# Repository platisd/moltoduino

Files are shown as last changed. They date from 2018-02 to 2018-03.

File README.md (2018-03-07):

# Moltoduino
Add programmable cores to your project and enable Hardware In the Loop (HIL) testing.

Stacked Moltoduinos

## What?
Moltoduino is an Arduino shield that enables the stacking of multiple ATMega328P microcontrollers. The microcontroller pins are broken out in two ways:
* Outwards, to enable their arbitrary connection to different components or other pins via cables.
* Inwards, to enable their connection to the respective pin of the bottommost Arduino via jumpers.

The firmware on the Moltoduino cores can be easily flashed by flipping a switch that sets them in programming mode and then using the bottommost Arduino as an ISP programmer. You can read more about the project on [platis.solutions](https://platis.solutions/blog/2018/02/22/moltoduino-extra-cores-hil-testing/).

## Why?
Moltoduino is essentially a barebones Arduino UNO in the form of a shield that can be easily reprogrammed. So, what can you do with it?

* Parallelize time-consuming or time-critical functionality (e.g. reading sensor data, playing sound)
* Have a dedicated microcontroller for computationally intensive operations (e.g. Fast Fourier Transform)
* Enable Hardware In the Loop (HIL) testing
* Get additional resources, such as I/O pins, external interrupts, Serial port, I2C bus etc
* Save physical space needed for applications that require a more than one microcontrollers (e.g. by stacking them instead placing them next to each other)

## How?
Moltoduino was initially created with the purpose of providing a stackable pin extension solution for Arduino boards. During development, another use case emerged which involved the shield being used for HIL testing.

The picture below illustrates how the pins of the shield's ATMega328P are broken out, highlighting them with **green**. In **red** one can find the bottom Arduino's pins. It becomes apparent that pins that follow the Arduino numbering convention can be easily connected via jumpers (e.g. D1 with D1) regardless of which specific Arduino board is in place (i.e. Mega or Uno). Furthermore, the shield's pins are also broken on the sides of the board so to be accessible when multiple Moltoduinos or other shields are stacked on top.

Moltoduino pin grouping

### Pin extension
Attaching a Moltoduino shield is more or less equivalent to placing an Arduino Uno on top of another Uno or Mega board. The cool part is that it doesn't take up any horizontal real estate. You program them to perform an individual task in parallel or connect the Arduinos together via Serial, I2C or otherwise to implement complex functionality.

The pins facing outward can interface with the external components while the inward facilitate connection to the bottom Arduino, especially via I2C or Serial.

### HIL testing
Moltoduino can be utilized to provide a _hobby-grade_ [HIL testing](http://www.hil-simulation.com/home/hil-testing.html) solution for your embedded project. Having two microcontrollers that are easily connected to each other it is possible to conduct HIL simulations. This is achieved by one microcontroller running the production code and the other running the HIL test which generates input for the system under test and reads its output.

Such a HIL test fixture allows you to automate system-level testing on your project by mimicking real-world input. This can be a difficult and laborious process, where the tester would have to manually provide the environment input and check the output so to verify the system. Check out the relevant [code examples](#code-examples) to see how a HIL implementation could look like.

### Programming Moltoduino
1. Have all switches (there is one on each Moltoduino), in the "operation" position instead of "programming" mode
2. In the Arduino IDE, upload the **ArduinoISP** sketch to the "bottom" Arduino
3. Open the sketch to upload to the Nth Moltoduino on the Arduino IDE
4. Make sure that "Arduino as ISP" is chosen under **Tools** :arrow_right: **Programmer**
5. Choose the Arduino Uno as the target board, under **Tools** :arrow_right: **Board** :arrow_right: **Arduino/Genuino UNO**
6. Put the switch in the "programming" position, on the Moltoduino(s) you wish to program
7. (If not previously done) Burn the bootloader, under **Tools** :arrow_right: **Burn bootloader**
8. Upload sketch using programmer, under **Sketch** :arrow_right: **Upload sketch using programmer**
9. Put the switch back in the "operation" position, otherwise uploading to the bottom Arduino will not be possible

## Code examples
For the code examples the [Smartcar shield](http://plat.is/smartcar) library will be used. You can easily download it via your Arduino IDE library manager.

### Controlling a Smartcar via UART
In this scenario, a [Smartcar](http://plat.is/smartcar) is being controlled via UART (e.g. an HC-06 Bluetooth dongle) and we want to verify its behavior. The HIL simulation will be running on an Arduino Mega while the system under test firmware will be uploaded onto a Moltoduino that is stacked on top.

**System under test**

The following code should be straight forward. Depending on the UART input the Smartcar should change speed and direction. We are steering the Smartcar with a servo motor while the speed is controlled by a brushed motor. We will be sending commands via UART and reading the PWM steering signal as well as the brushed motor control signals in order to verify the Smartcar's intended behavior.

```cpp
#include <Smartcar.h>

const int SERVO_PIN = 3;
const int FORWARD_PIN = 8;
const int BACKWARD_PIN = 7;
const int THROTTLE_PIN = 6;
const int fSpeed = 70; // 70% of the full speed forward
const int bSpeed = -70; // 70% of the full speed backward
const int lDegrees = -50; // Degrees to turn left
const int rDegrees = 50; // Degrees to turn right

// Initialize the car, that uses a servo motor for steering
// and a brushed DC motor to pins 8,7 (direction) and 6 (PWM) for throttling
Car car(useServo(SERVO_PIN), useDCMotor(FORWARD_PIN, BACKWARD_PIN, THROTTLE_PIN));

void setup() {
  Serial.begin(9600);
  car.begin(); // Initialize the car using the encoders and the gyro
}

void loop() {
  handleInput();
}

void handleInput() { // Handle serial input if there is any
  if (Serial.available()) {
    char input = Serial.read();
    switch (input) {
      case 'l': // Turn counter-clockwise going forward
        car.setSpeed(fSpeed);
        car.setAngle(lDegrees);
        break;
      case 'r': // Turn clock-wise
        car.setSpeed(fSpeed);
        car.setAngle(rDegrees);
        break;
      case 'f': // Go ahead
        car.setSpeed(fSpeed);
        car.setAngle(0);
        break;
      case 'b': // Go back
        car.setSpeed(bSpeed);
        car.setAngle(0);
        break;
      default: // If you receive something that you don't know, just stop
        car.setSpeed(0);
        car.setAngle(0);
    }
  }
}
```

**HIL simulation**

In this HIL test we need to simulate the input to the system (i.e. UART commands) and then observe its output (i.e. pin states and PWM signal) to verify production code's correct behavior. Moreover, jumpers are used to enable interaction between the system under test and the HIL simulation. The jumper placement is illustrated in the table below.

| HIL simulation | System Under Test | Purpose |
| :----: |:----: |:----: |
| TX |  RX | Transmit UART commands to the SUT |
| 3 |  3 | Read servo motor's PWM signal |
| 7 |  7 | Read motor control pin |
| 8 |  8 | Read motor control pin |

```cpp
// Simulation pin configuration
const int STEERING_PIN = 3;
const int FORWARD_PIN = 8; // Car goes forward when set HIGH
const int BACKWARD_PIN = 7; // Car goes backward when set HIGH
const int THROTTLE_PIN = 6;
// UART commands
const char CAR_FORWARD = 'f';
const char CAR_BACKWARD = 'b';
const char CAR_LEFT = 'l';
const char CAR_RIGHT = 'r';
const char CAR_STOP = 's';
// Expected steering degrees
const int LEFT = -50;
const int RIGHT = 50;
const int STRAIGHT = 0;
// Other variables and structures
enum Throttle {
  FORWARD,
  BACKWARD,
  STOPPED,
};

bool isThrottle(Throttle expectedThrottle) {
  Throttle actualThrottle = STOPPED;
  if (digitalRead(FORWARD_PIN) && !digitalRead(BACKWARD_PIN)) {
    actualThrottle = FORWARD;
  } else if (!digitalRead(FORWARD_PIN) && digitalRead(BACKWARD_PIN)) {
    actualThrottle = BACKWARD;
  }

  return actualThrottle == expectedThrottle;
}

bool isSteering(int expectedAngle) {
  int pwm = pulseIn(STEERING_PIN, HIGH);
  // Map the PWM signal to a 0 to 180 scale
  const int MIN_PWM = 540;
  const int MAX_PWM = 2390;
  int measuredAngle = map(pwm, MIN_PWM, MAX_PWM, 0, 180);
  // Offset the angle by 90 to get an angle between -90 and 90
  measuredAngle -= 90;
  int absoluteDelta = expectedAngle > measuredAngle ?
                      expectedAngle - measuredAngle : measuredAngle - expectedAngle;
  // We are expecting some error in these measurements so let's define an acceptable error margin
  const int ERROR_MARGIN = 5;

  return absoluteDelta < ERROR_MARGIN;
}

void runSmartcarHIL(const char* testName, const char command, Throttle throttle, const int steering) {
  Serial.print("RUNNING: ");
  Serial.println(testName);
  // Send command
  Serial.print("Sending command: ");
  Serial.print(command);
  Serial.flush(); // Make sure we have finished sending
  // Wait a bit to make sure the command has been processed
  const unsigned long TEST_DELAY = 100;
  delay(TEST_DELAY);
  String result = isThrottle(throttle) && isSteering(steering) ? "PASSED" : "FAILED";
  Serial.print("\nRESULT: ");
  Serial.println(result);
  Serial.println("----");
}

void goForward_test() {
  auto UARTcommand = CAR_FORWARD;
  auto expectedThrottle = FORWARD;
  auto expectedSteering = STRAIGHT;
  runSmartcarHIL(__func__, UARTcommand, expectedThrottle, expectedSteering);
}

void goBackward_test() {
  auto UARTcommand = CAR_BACKWARD;
  auto expectedThrottle = BACKWARD;
  auto expectedSteering = STRAIGHT;
  runSmartcarHIL(__func__, UARTcommand, expectedThrottle, expectedSteering);
}

void turnLeft_test() {
  auto UARTcommand = CAR_LEFT;
  auto expectedThrottle = FORWARD;
  auto expectedSteering = LEFT;
  runSmartcarHIL(__func__, UARTcommand, expectedThrottle, expectedSteering);
}

void turnRight_test() {
  auto UARTcommand = CAR_RIGHT;
  auto expectedThrottle = FORWARD;
  auto expectedSteering = RIGHT;
  runSmartcarHIL(__func__, UARTcommand, expectedThrottle, expectedSteering);
}

void stop_test() {
  auto UARTcommand = CAR_STOP;
  auto expectedThrottle = STOPPED;
  auto expectedSteering = STRAIGHT;
  runSmartcarHIL(__func__, UARTcommand, expectedThrottle, expectedSteering);
}

void setup() {
  pinMode(FORWARD_PIN, INPUT);
  pinMode(BACKWARD_PIN, INPUT);
  pinMode(STEERING_PIN, INPUT);
  Serial.begin(9600);
  Serial.println("====================");
  Serial.println("Starting HIL test suite");
  Serial.println("====================");

  goForward_test();
  goBackward_test();
  turnLeft_test();
  turnRight_test();
  stop_test();
}

void loop() {
}
```

### Controlling a light based on ultrasound sensor distance measurements
In this scenario, an `HC-SR04` ultrasound sensor is being used to measure distances. When an object is detected close enough a light turns on. Yet again, the HIL simulation will be running on an Arduino Mega while the system under test firmware will be uploaded onto a Moltoduino that is stacked on top.

**System under test**

Below you can find a simplified implementation of the typical use case in which a light needs to be turned on when an object is detected at a nearby distance otherwise it should be off. The `HC-SR04` class of [Smartcar shield](http://plat.is/smartcar) library is utilized to conduct the measurements.

```cpp
#include <Smartcar.h>

SR04 sensor;
const int TRIGGER_PIN = 2;
const int ECHO_PIN = 3;
const int LIGHT_PIN = 9;
const int MIN_OBSTACLE_DISTANCE = 15; // In centimeters

void setup() {
  sensor.attach(TRIGGER_PIN, ECHO_PIN);
  pinMode(LIGHT_PIN, OUTPUT);
}

void loop() {
  auto distance = sensor.getDistance();
  // If there is an obstacle nearby turn the light on
  if (distance > 0 && distance < MIN_OBSTACLE_DISTANCE) {
    digitalWrite(LIGHT_PIN, HIGH);
  } else {
    digitalWrite(LIGHT_PIN, LOW);
  }
  delay(100);
}
```

**HIL simulation**

In this HIL test we need to simulate the `HC-SR04` ultrasound sensor's input to the system and then observe its output (i.e. the pin that controls the state of the light). Particularly, we observe (via an interrupt) the incoming signals from the trigger pin of the system under test, an event which designates that a measurement has been initiated. Next, we simulate the sensor input by calculating and producing a pulse of equal length to the one that would have been generated, should there have been an actual sensor and an object. Finally, we verify the digital pin that controls the light is in the appropriate state.

Jumpers are used to enable interaction between the system under test and the HIL simulation. The jumper placement is illustrated in the table below.

| HIL simulation | System Under Test | Purpose |
| :----: |:----: |:----: |
| 2 |  2 | Read trigger signal  |
| 3 |  3 | Generate echo pulse  |
| 9 |  9 | Read light pin state |

```cpp
const int TRIGGER_PIN = 2;
const int ECHO_PIN = 3;
const int LIGHT_PIN = 9;

volatile unsigned long echoDuration = 0;

void generateEcho() {
  if (echoDuration == 0) {
    // If no echo duration has been set or set to 0
    // then return immediately as no pulse is to be generated
    return;
  }
  digitalWrite(ECHO_PIN, LOW); // Set LOW first for cleaner signal
  delayMicroseconds(3);
  // Simulate the echo pulse of an HC-SR04 sensor
  digitalWrite(ECHO_PIN, HIGH);
  delayMicroseconds(echoDuration);
  digitalWrite(ECHO_PIN, LOW);
}

/**
   Accordig to the HC-SR04 datasheet (https://goo.gl/b22dp3) the formula to
   determine the distance in centimeters is: cm = uSec / 58
   We need to calculate the length of the pulse in microseconds
   that we has to be generated to simulate a specific distance in cm.
*/
void setEchoPulseDurationFor(unsigned int cm) {
  noInterrupts();
  echoDuration = cm * 58;
  interrupts();
}

void runUltrasoundHIL(const char* testName, int obstacleDistance, int expectedLEDState) {
  Serial.print("RUNNING: ");
  Serial.println(testName);
  setEchoPulseDurationFor(obstacleDistance);
  const unsigned long TEST_DELAY = 300;
  delay(TEST_DELAY); // Wait a bit for a new measurement to start
  String result = digitalRead(LIGHT_PIN) == expectedLEDState ? "PASSED" : "FAILED";
  Serial.print("\nRESULT: ");
  Serial.println(result);
  Serial.println("----");
}

void whenObstacleNear_lightTurnsOn_test() {
  auto obstacleDistance = 10;
  auto expectedLEDState = HIGH;
  runUltrasoundHIL(__func__, obstacleDistance, expectedLEDState);
}

void whenObstacleFar_lightTurnsOff_test() {
  auto obstacleDistance = 15;
  auto expectedLEDState = LOW;
  runUltrasoundHIL(__func__, obstacleDistance, expectedLEDState);
}

void whenNoObstacle_lightTurnsOff_test() {
  auto obstacleDistance = 0;
  auto expectedLEDState = LOW;
  runUltrasoundHIL(__func__, obstacleDistance, expectedLEDState);
}

void setup() {
  pinMode(LIGHT_PIN, INPUT);
  pinMode(TRIGGER_PIN, INPUT);
  pinMode(ECHO_PIN, OUTPUT);
  // Setup interrupt for trigger pin which goes HIGH when a measurement begins
  attachInterrupt(digitalPinToInterrupt(TRIGGER_PIN), generateEcho, FALLING);
  Serial.begin(9600);
  Serial.println("====================");
  Serial.println("Starting HIL test suite");
  Serial.println("====================");

  whenObstacleNear_lightTurnsOn_test();
  whenObstacleFar_lightTurnsOff_test();
  whenNoObstacle_lightTurnsOff_test();
}

void loop() {
}
```

## Bill Of Materials
| Quantity | Value | Device | Package |
|---|--- |---|---|
| 1 | Moltoduino PCB | ARDUINO_R3_ICSP | ARDUINOR3_ICSP |
| 1 | ATMEGA328P_PDIP  | ATMEGA328P_PDIP | DIL28-3 |
| 1 | BC547 | TRANSISTOR_NPNBC547 | TO-92-AMMO |
| 3 | 100nf | DIP-CERAMIC-DISC-100NF-50V-Y5V(D5.0MM) | CERAMIC-2.54 |
| 1 | 150Ω | DIP-RES-1K-5%-1/4W(PR-D2.3XL6.5MM) | PR-D2.3XL6.5MM |
| 1 | 16MHZ | DIP-CRYSTAL-16MHZ-18PF-30PPM-50R(HC49US)  | HC49US |
| 1 | 1K | DIP-RES-1K-5%-1/4W(PR-D2.3XL6.5MM) | PR-D2.3XL6.5MM |
| 2 | 22pf | DIP-CERAMIC-DISC-22PF-50V-10%-NPO(D4.0MM) | CERAMIC-2.54 |
| 1 | 2x16p-2.54 | DIP-BLACK-MALE-HEADER-VERT(2X16P-2.54) | H2X16-2.54 |
| 1 | 2x6p-2.54 | DIP-BLACK-MALE-HEADER(2X6P-2.54) | H2X6-2.54 |
| 2 | 4.7K | DIP-RES-4.7K-5%-1/4W(PR-D2.3XL6.5MM) | PR-D2.3XL6.5MM |
| 4 | 7p-2.54-90d | DIP-BLACK-MALE-HEADER(7P-2.54-90D) | H7-2.54-90D-MALE |
| 1 | AD595AQ-DIP14 | 74HC4066(DIP14) | DIP14-2.54-17.24X6.35MM |
| 1 | SK-12D01 | DIP-TOGGLE-SWITCH-ON-ON(3+2P-8.8X4.6MM) | SW5-2.0-8.8X4.4X4.7MM-90D |
| 1 | SR302DC | DIP-LED-RED-RED(2P-D3MM) | LED2-2.54-D3.0MM |
| 1 | TS-1101F | DIP-BUTTON-FRONT-WHITE(2P-3.4X6MM) | SW2-3.4X6.0X3.55MM-90D |

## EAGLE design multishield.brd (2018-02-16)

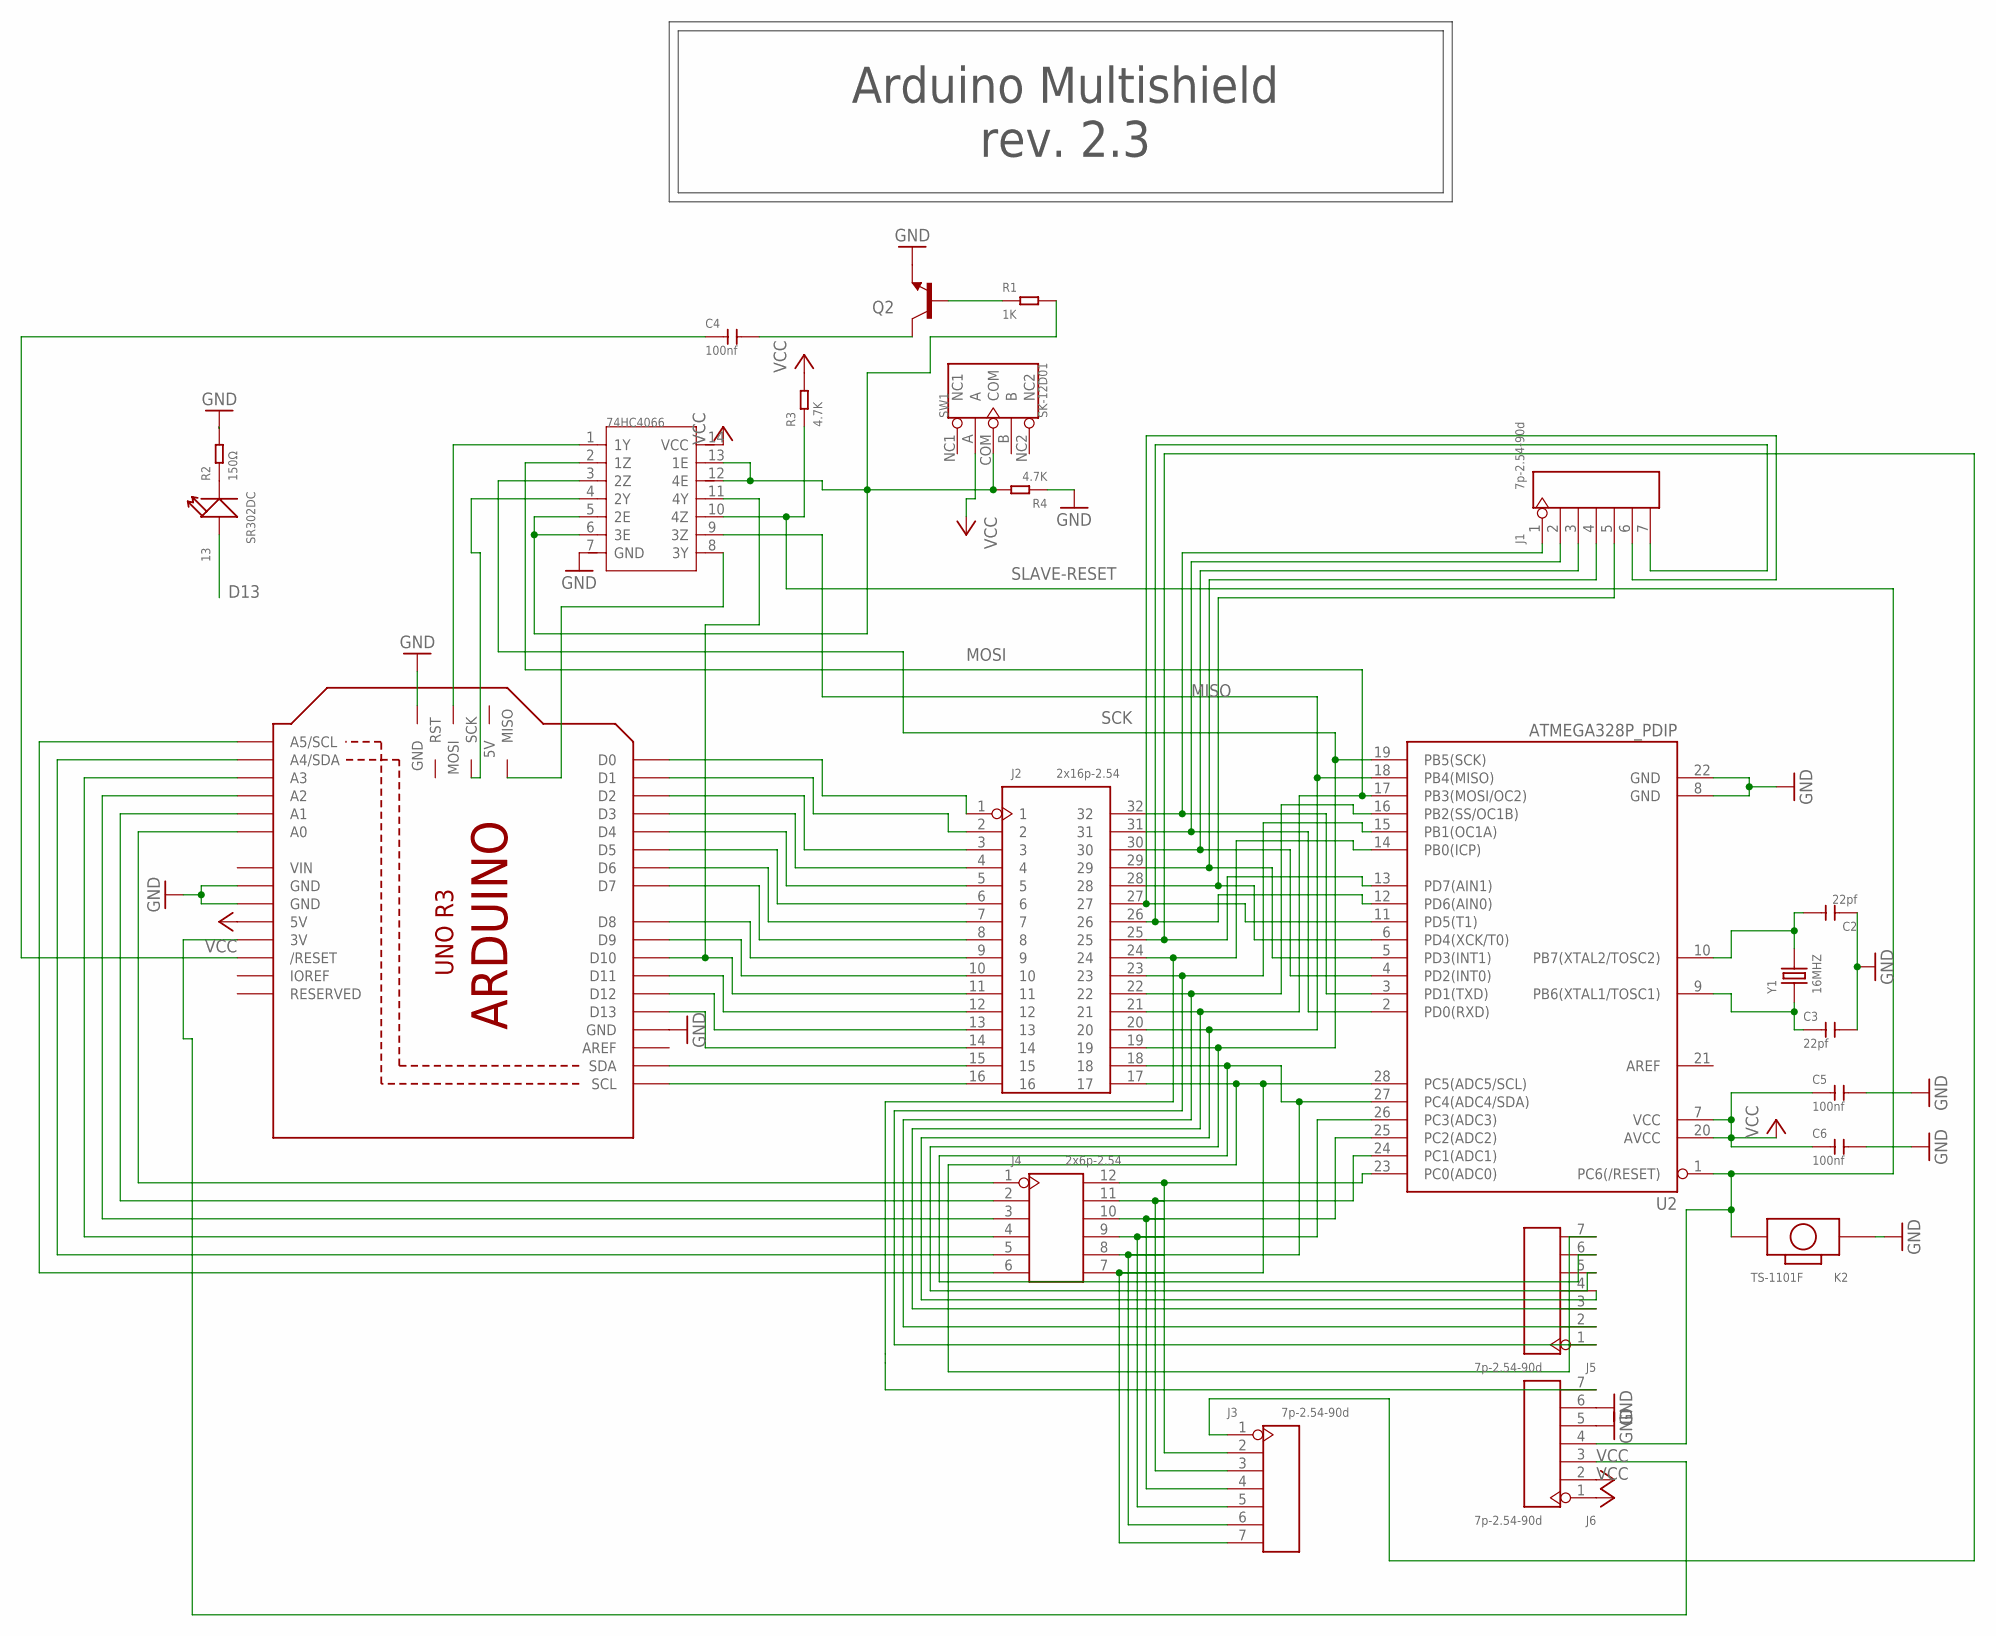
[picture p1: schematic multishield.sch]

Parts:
13: SR302DC; LED2-2.54-D3.0MM
C2, C3: 22pf; CERAMIC-2.54
C4, C5, C6: 100nf; CERAMIC-2.54
J1, J3, J5, J6: 7p-2.54-90d; H7-2.54-90D-MALE
J2: 2x16p-2.54; H2X16-2.54
J4: 2x6p-2.54; H2X6-2.54
K2: TS-1101F; SW2-3.4X6.0X3.55MM-90D
M1: ARDUINO_R3_ICSP; ARDUINOR3_ICSP
Q2: TRANSISTOR_NPNBC547; TO-92-AMMO
R1: 1K; PR-D2.3XL6.5MM
R2: 150Ω; PR-D2.3XL6.5MM
R3, R4: 4.7K; PR-D2.3XL6.5MM
SW1: SK-12D01; SW5-2.0-8.8X4.4X4.7MM-90D
U1: AD595AQ-DIP14; DIP14-2.54-17.24X6.35MM
U2: ATMEGA328P_PDIP; DIL28-3
Y1: 16MHZ; HC49US

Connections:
D9A: J2.10, M1.D9
D9B: J2.23, J5.1, U2.15 (PB1(OC1A))
GND: C2.1, C3.2, C5.2, C6.2, J6.5, J6.6, K2.P$1 (1), M1.GND, M1.GND@1 (GND), M1.GND@2 (GND), M1.GND@3 (GND), Q2.3 (E), R2.2, R4.1, U1.7 (GND), U2.8 (GND), U2.22 (GND)
MISO: J2.20, J5.4, U1.9 (3Z), U2.18 (PB4(MISO))
MOSI: J2.21, J5.3, U1.2 (1Z), U2.17 (PB3(MOSI/OC2))
unnamed: J2.1, M1.D0
unnamed: J2.2, M1.D1
unnamed: J2.3, M1.D2
unnamed: J2.4, M1.D3
unnamed: J2.5, M1.D4
unnamed: J2.6, M1.D5
unnamed: J2.7, M1.D6
unnamed: J2.8, M1.D7
unnamed: J2.9, M1.D8
unnamed: 13.K (-), R2.1
unnamed: J2.11, M1.D10, U1.11 (4Y)
unnamed: J2.12, M1.D11
unnamed: J2.13, M1.D12
unnamed: J2.14, M1.D13
unnamed: J2.15, M1.SDA
unnamed: J2.16, M1.SCL
unnamed: J1.1, J2.32, U2.3 (PD1(TXD))
unnamed: J1.2, J2.31, U2.2 (PD0(RXD))
unnamed: J1.3, J2.30, U2.4 (PD2(INT0))
unnamed: J1.4, J2.29, U2.5 (PD3(INT1))
unnamed: J1.5, J2.28, U2.6 (PD4(XCK/T0))
unnamed: J1.6, J2.27, U2.11 (PD5(T1))
unnamed: J4.1, M1.A0
unnamed: J2.25, J3.1, U2.13 (PD7(AIN1))
unnamed: J2.24, J6.7, U2.14 (PB0(ICP))
unnamed: J2.22, J5.2, U2.16 (PB2(SS/OC1B))
unnamed: C4.2, Q2.1 (C)
unnamed: C4.1, M1.RESET (/RESET)
unnamed: Q2.2 (B), R1.1
unnamed: M1.MOSI, U1.1 (1Y)
unnamed: M1.SCK, U1.4 (2Y)
unnamed: J1.7, J2.26, U2.12 (PD6(AIN0))
unnamed: J4.2, M1.A1
unnamed: J4.3, M1.A2
unnamed: J4.4, M1.A3
unnamed: J3.2, J4.12, U2.23 (PC0(ADC0))
unnamed: J3.3, J4.11, U2.24 (PC1(ADC1))
unnamed: J3.4, J4.10, U2.25 (PC2(ADC2))
unnamed: J3.5, J4.9, U2.26 (PC3(ADC3))
unnamed: J2.18, J3.6, J4.8, J5.6, U2.27 (PC4(ADC4/SDA))
unnamed: J2.17, J3.7, J4.7, J5.7, U2.28 (PC5(ADC5/SCL))
unnamed: J4.5, M1.A4 (A4/SDA)
unnamed: J4.6, M1.A5 (A5/SCL)
unnamed: M1.MISO, U1.8 (3Y)
unnamed: J6.3, M1.3V
unnamed: C2.2, U2.10 (PB7(XTAL2/TOSC2)), Y1.2
unnamed: R1.2, R4.2, SW1.COM, U1.5 (2E), U1.6 (3E), U1.12 (4E), U1.13 (1E)
unnamed: C3.1, U2.9 (PB6(XTAL1/TOSC1)), Y1.1
SCK: 13.A (+), J2.19, J5.5, U1.3 (2Z), U2.19 (PB5(SCK))
SLAVE-RESET: J6.4, K2.P$2 (2), R3.1, U1.10 (4Z), U2.1 (PC6(/RESET))
VCC: C5.1, C6.1, J6.1, J6.2, M1.5V, R3.2, SW1.A, U1.14 (VCC), U2.7 (VCC), U2.20 (AVCC)
VIN: M1.VIN

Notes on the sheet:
Arduino Multishield rev. 2.3
D13

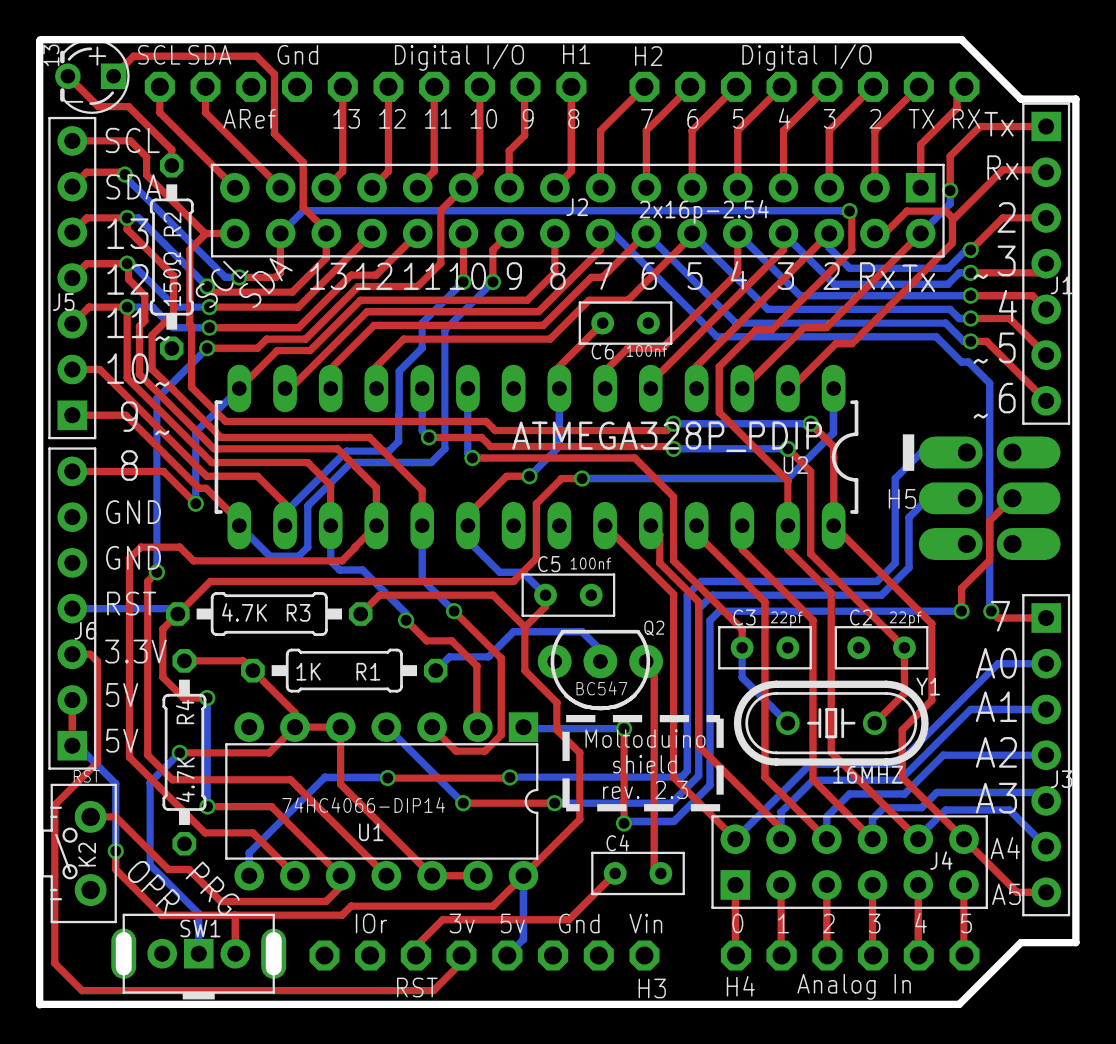
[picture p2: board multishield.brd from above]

Board: 2 copper layers, 57.6 x 53.6 mm, 24 parts (0 on the bottom side), 56 nets.

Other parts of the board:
U$4: OSHWLOGO_BACK_0.2

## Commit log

2016-02-24 initial upload
    [multishield.brd, multishield.sch]
2016-02-25 adding shield with breakouts
    [multishield.brd, multishield.sch]
2016-02-26 added most of the things by now, minor aesthetic additions left for rev.0
    [multishield.brd, multishield.sch]
2016-02-26 various improvements + clock
    [multishield.brd, multishield.sch]
2016-02-26 part replacements and bom
    [multishield.brd, multishield.sch]
2016-03-02 rev. 0, BOM with prices
    [multishield.brd]
2016-03-28 adding 100nF capacitors and minor other changes
    [multishield.brd, multishield.sch]
2016-03-30 rev 1
    [multishield.brd, multishield.sch]
2016-04-06 latest updates
    [multishield.brd, multishield.sch]
2016-04-06 7pin angled headers instead
    [multishield.brd, multishield.sch]
2016-04-06 moved atmega328 to the left, to make more space for the isp header soldering
    [multishield.brd]
2016-04-06 moved atmega328 further to the left
    [multishield.brd]
2016-04-20 7-pin headers moved to the edges, some wiring refactored
    [multishield.brd, multishield.sch]
2016-04-22 reset pin added, various changes (in pin packages to make soldering easier
    [multishield.brd, multishield.sch]
2016-04-28 various improvements and addition of LED at D9
    [multishield.brd, multishield.sch]
2016-04-29 changed 0 and 1 labels to rx and tx
    [multishield.brd, multishield.sch]
2016-05-01 no more short circuiting while switch in the middle position
    [multishield.brd, multishield.sch]
2016-06-08 version 2.2 (Led on D13)
    [multishield.brd, multishield.sch]
2018-02-16 Small changes for rev. 2.3
    [multishield.brd, multishield.sch]
2018-02-21 Update README
    * Add section
    * Add Smartcar control via UART code example
2018-02-21 Add BOM
2018-02-21 Refactor BOM
    * Remove SKUs
    * Move Moltoduino shield and atmega328p chip to the top
2018-02-21 Remove BOM in gnumeric format
2018-02-21 Add ultrasound sensor distance HIL test example
2018-02-22 Fix BOM entries
2018-02-22 Update BOM
2018-02-23 Add min and max PWM frequency variables
2018-03-07 Emphasize the Arduino IDE options

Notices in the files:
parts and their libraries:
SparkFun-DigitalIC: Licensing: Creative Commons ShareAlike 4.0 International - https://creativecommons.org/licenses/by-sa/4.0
